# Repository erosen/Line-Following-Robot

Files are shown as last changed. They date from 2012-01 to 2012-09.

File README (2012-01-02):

The Rutgers IEEE Robotics club is proud to announce a brand new line following robot kit for the 2010-2011 school year.  This kit is easier to both assemble and program.  It features an Arduino Decimilia brain board, a Line following Robot Shield, a Line sensor board, and Solarbotics GM9 motors and wheels.   It includes everything you need to get your robot up and running.  All you need to do is supply the chassis and write your own line following program. 

This kit is the cheapest and most customizable robotics kit possible. To assemble the kit, all you need to do is solder through-hole components.   It is suitable for beginners who have never soldered before and for masters who want a quick platform with which to build their robot. We will be holding Workshop sessions each week at the start of the semester to teach people how to assemble and program their kit.

The Line following shield sits on top of the Arduino board and provides a clean interface to the Arduino microcontroller for your motors and line sensor. The line following shield includes a motor driver to control your GM8 motors.  The line following board uses a IR Emitter and Phototransistor pair to accurately and easily locate the line.

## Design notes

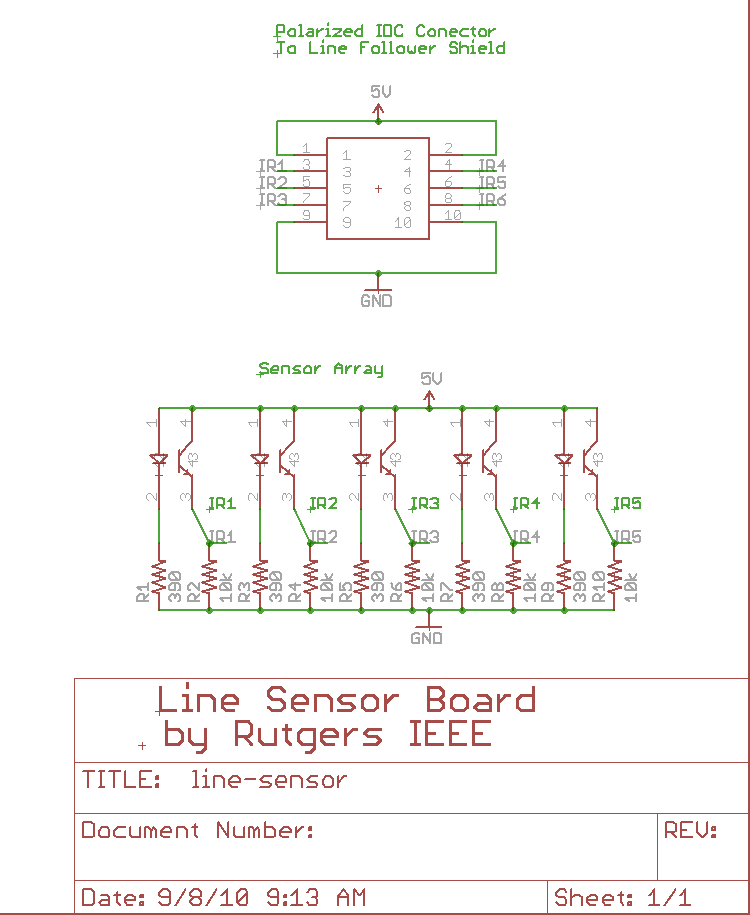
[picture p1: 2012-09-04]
Line-Following-Robot/Documentation/line_sensor_schematic.png

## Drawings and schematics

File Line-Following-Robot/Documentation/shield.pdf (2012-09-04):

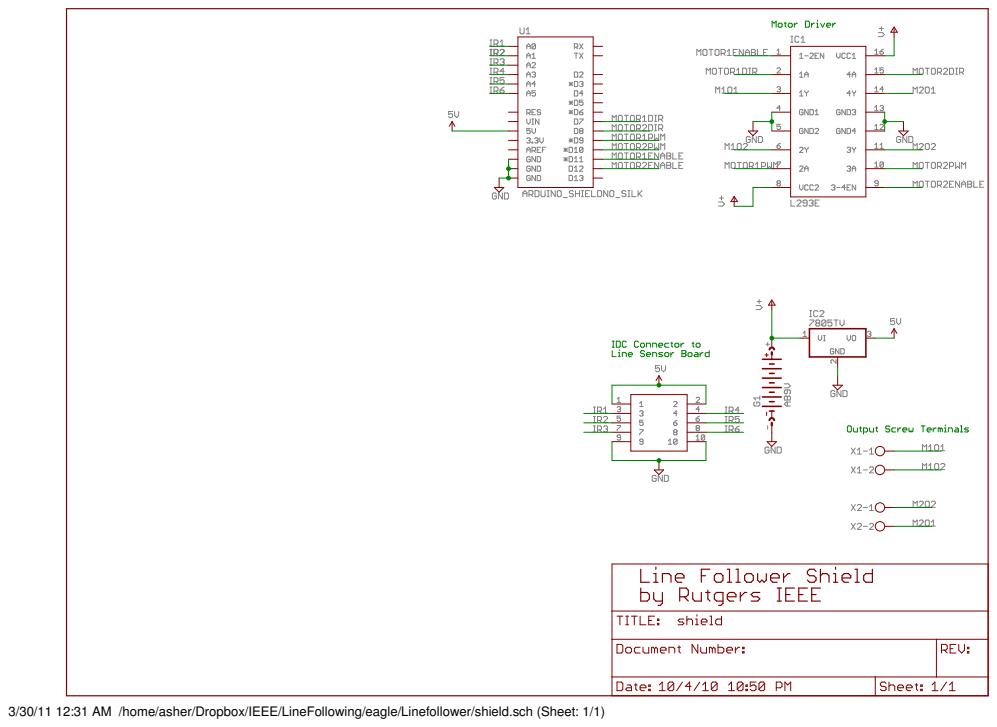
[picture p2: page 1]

3/30/11 12:31 AM /home/asher/Dropbox/IEEE/LineFollowing/eagle/Linefollower/shield.sch (Sheet: 1/1)

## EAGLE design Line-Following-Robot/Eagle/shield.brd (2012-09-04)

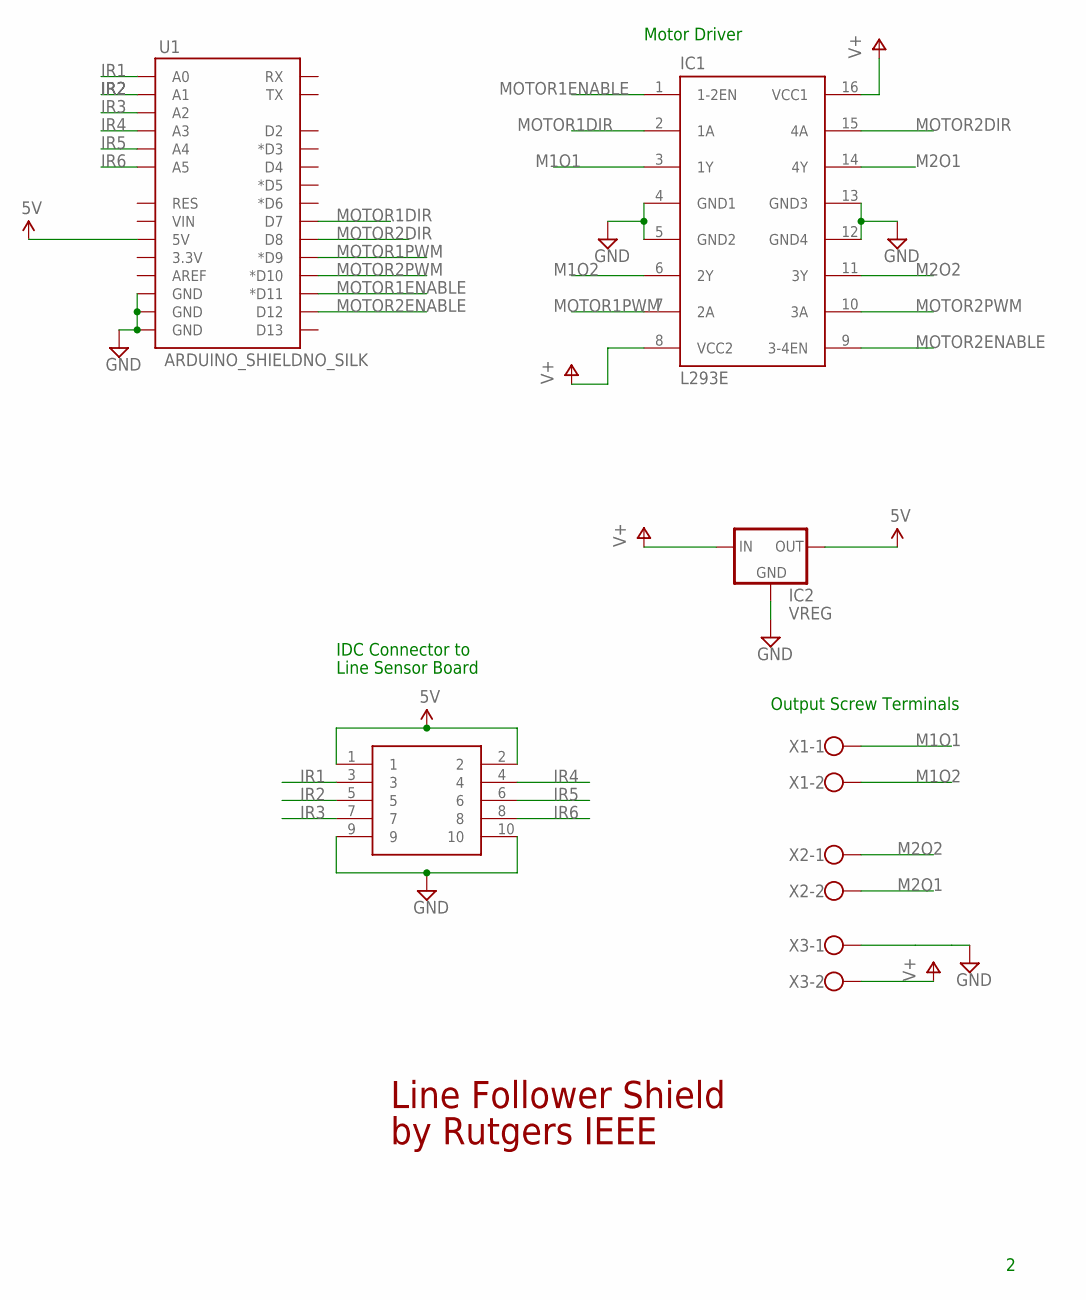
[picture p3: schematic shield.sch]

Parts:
IC1: L293E; DIL16
IC2: VREG; TO-220-ALT
U1: ARDUINO_SHIELDNO_SILK; DUEMILANOVE_VIAS
U$3: 2X5-PHEADER; 2X5-SHROUDED-HEADER
X1, X2, X3: W237-102

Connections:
5V: IC2.OUT, U1.5V, U$3.1, U$3.2
9V: IC1.8 (VCC2), IC1.16 (VCC1), IC2.IN, X3.2
GND: IC1.4 (GND1), IC1.5 (GND2), IC1.12 (GND4), IC1.13 (GND3), IC2.GND, U1.GND@0 (GND), U1.GND@1 (GND), U1.GND@2 (GND), U$3.9, U$3.10, X3.1
IR1: U1.A0, U$3.3
IR2: U1.A1, U$3.5
IR3: U1.A2, U$3.7
IR4: U1.A3, U$3.4
IR5: U1.A4, U$3.6
IR6: U1.A5, U$3.8
M1O1: IC1.3 (1Y), X1.1
M1O2: IC1.6 (2Y), X1.2
M2O1: IC1.14 (4Y), X2.2
M2O2: IC1.11 (3Y), X2.1
MOTOR1DIR: IC1.2 (1A), U1.D7
MOTOR1ENABLE: IC1.1 (1-2EN), U1.D11 (*D11)
MOTOR1PWM: IC1.7 (2A), U1.D9 (*D9)
MOTOR2DIR: IC1.15 (4A), U1.D8
MOTOR2ENABLE: IC1.9 (3-4EN), U1.D12
MOTOR2PWM: IC1.10 (3A), U1.D10 (*D10)

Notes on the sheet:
Output Screw Terminals
IDC Connector to
Line Sensor Board
Motor Driver
Line Follower Shield
by Rutgers IEEE

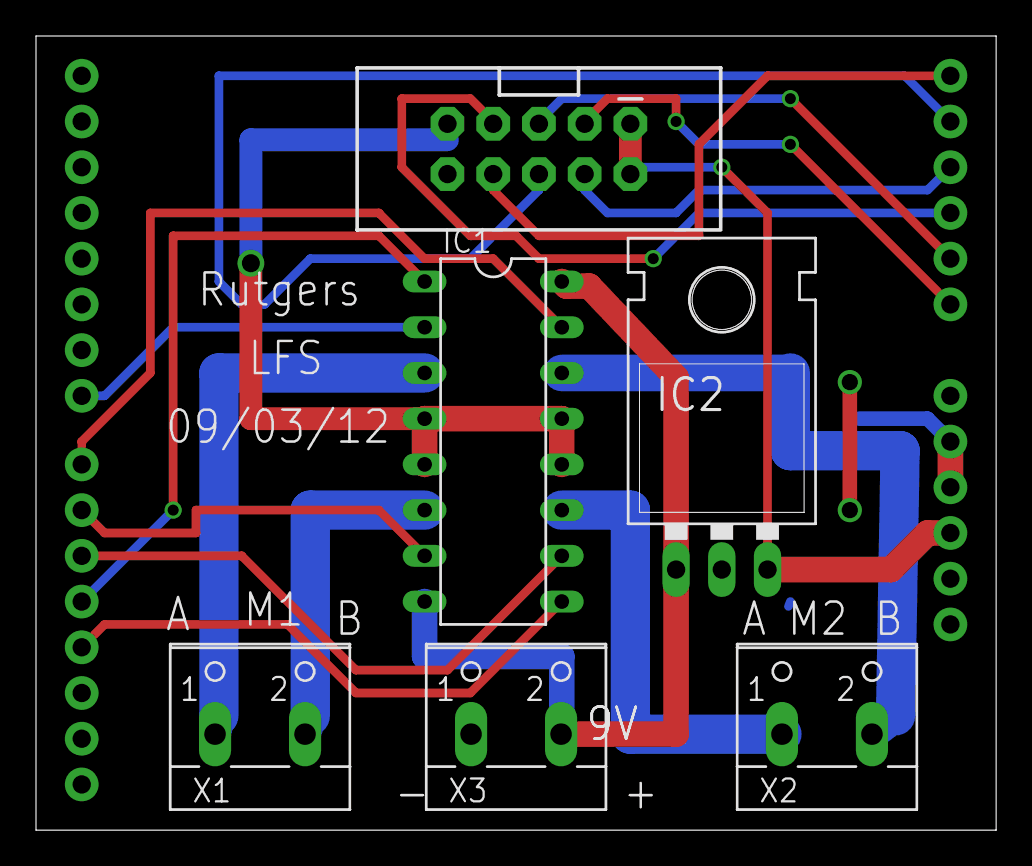
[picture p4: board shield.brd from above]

Board: 2 copper layers, 53.3 x 44.1 mm, 7 parts (0 on the bottom side), 19 nets.

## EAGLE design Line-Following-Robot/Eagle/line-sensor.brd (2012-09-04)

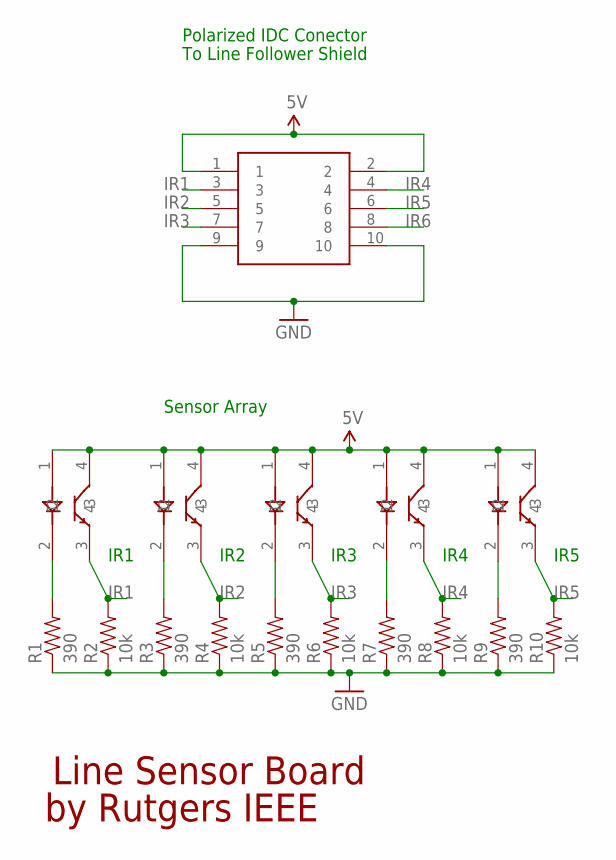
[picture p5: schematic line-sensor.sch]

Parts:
R1, R3, R5, R7, R9: 390; AXIAL-0.3
R2, R4, R6, R8, R10: 10k; AXIAL-0.3
U$1: IR1; RPR220
U$2: IR2; RPR220
U$3: IR3; RPR220
U$4: IR4; RPR220
U$5: IR5; RPR220
U$8: 2X5-PHEADER; 2X5-SHROUDED-HEADER

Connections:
5V: U$1.1, U$1.4, U$2.1, U$2.4, U$3.1, U$3.4, U$4.1, U$4.4, U$5.1, U$5.4, U$8.1, U$8.2
GND: R1.P$1 (1), R2.P$1 (1), R3.P$1 (1), R4.P$1 (1), R5.P$1 (1), R6.P$1 (1), R7.P$1 (1), R8.P$1 (1), R9.P$1 (1), R10.P$1 (1), U$8.9, U$8.10
IR1: R2.P$2 (2), U$1.3, U$8.3
IR2: R4.P$2 (2), U$2.3, U$8.5
IR3: R6.P$2 (2), U$3.3, U$8.7
IR4: R8.P$2 (2), U$4.3, U$8.4
IR5: R10.P$2 (2), U$5.3, U$8.6
IR6: U$8.8
unnamed: R1.P$2 (2), U$1.2
unnamed: R3.P$2 (2), U$2.2
unnamed: R5.P$2 (2), U$3.2
unnamed: R7.P$2 (2), U$4.2
unnamed: R9.P$2 (2), U$5.2

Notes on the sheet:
IR1
IR2
IR3
IR4
IR5
Polarized IDC Conector
To Line Follower Shield
Sensor Array
Line Sensor Board
by Rutgers IEEE

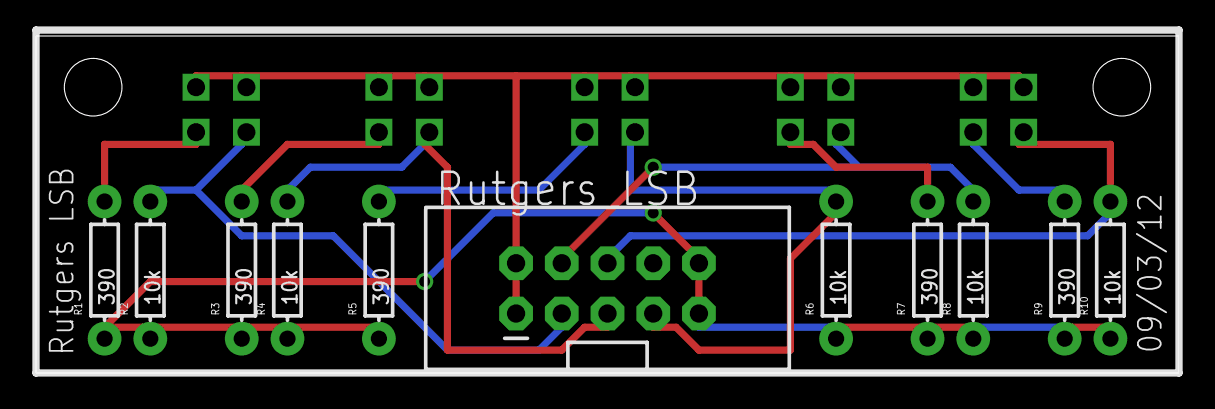
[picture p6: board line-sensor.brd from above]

Board: 2 copper layers, 63.5 x 18.7 mm, 16 parts (0 on the bottom side), 12 nets.

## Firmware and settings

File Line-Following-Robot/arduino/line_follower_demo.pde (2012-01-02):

// Arduino Language Reference
// http://arduino.cc/en/Reference/HomePage

#define motor1Dir 7
#define motor2Dir 8
#define motor1PWM 9
#define motor2PWM 10
#define motor1Enable 11
#define motor2Enable 12



void setMotorVel(int dirPin, int pwmPin, int velocity){
  if (velocity >= 255) velocity = 255;
  if (velocity <= -255) velocity = -255;

  if (velocity == 0)
  {
    digitalWrite(dirPin, HIGH);
    digitalWrite(pwmPin, HIGH);
  }
  else if(velocity <0){  // Reverse
    digitalWrite(dirPin, HIGH);
    analogWrite(pwmPin, 255+velocity);
  }
  else if(velocity >0){ // Forward
    digitalWrite(dirPin,LOW);
    analogWrite(pwmPin, velocity);
  }
}


void setLeftMotorSpeed(int velocity)
{
  setMotorVel(motor1Dir, motor1PWM, -velocity);

}

void setRightMotorSpeed(int velocity){
  setMotorVel(motor2Dir, motor2PWM, -velocity);
}

void initMotorDriver()
{
  pinMode(motor1Dir, OUTPUT);
  pinMode(motor2Dir, OUTPUT);

  pinMode(motor1Enable, OUTPUT);
  pinMode(motor2Enable, OUTPUT);
  digitalWrite(motor1Enable,HIGH);
  digitalWrite(motor2Enable,HIGH);
  setLeftMotorSpeed(0); // make sure the motors are stopped
  setRightMotorSpeed(0);
}




void goForward()
{
  setLeftMotorSpeed(255);
  setRightMotorSpeed(255);
}

void goRight()
{
  setLeftMotorSpeed(255);
  setRightMotorSpeed(-255);
}

void goLeft()
{
  setLeftMotorSpeed(-255);
  setRightMotorSpeed(255);
}


void setup(){
  Serial.begin(115200); //Set the buad rate for the serial com. 

  // prints title with ending line break 
  Serial.println("Line Sensor boar Sensor test"); 
  initMotorDriver();
  
  
}


#define line_thresh 100


void loop(){
 int sensors[5];

 for (int i =0; i <5; i++)
  {
    sensors[i] = analogRead(i);
  }

  Serial.print("Sensor Values : " );

  for (int i =0; i <4; i++)
  {
    Serial.print( sensors[i]);
    Serial.print(" " );
  }

  Serial.println(" ");

  if(( sensors[3] < line_thresh) || (sensors[4] <line_thresh))  // 250 is a measured threshold between white & black
  {
    goLeft();
    delay(30);
  }
   else if(( sensors[0] <line_thresh) || (sensors[1] <line_thresh))
  {
    goRight();
    delay(30);
  }
  else{
  goForward();
  
  delay(100);
  }
  
  
}

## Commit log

2012-01-02 arduino code
2012-09-04 Board updates for Fall 2012
    Better placement for 5v regulator
    [line-sensor.brd, line-sensor.sch, shield.brd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]

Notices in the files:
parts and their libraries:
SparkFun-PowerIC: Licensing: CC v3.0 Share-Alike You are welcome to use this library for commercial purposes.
